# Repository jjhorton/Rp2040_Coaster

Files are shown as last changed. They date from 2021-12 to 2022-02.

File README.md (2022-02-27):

# Rp2040_Coaster

## Introduction
The idea was to build a light up drinks coaster, which would sit under a clear glass drinks bottle and light it up in a colorful display, only when the bottle is on top. 

## Building 

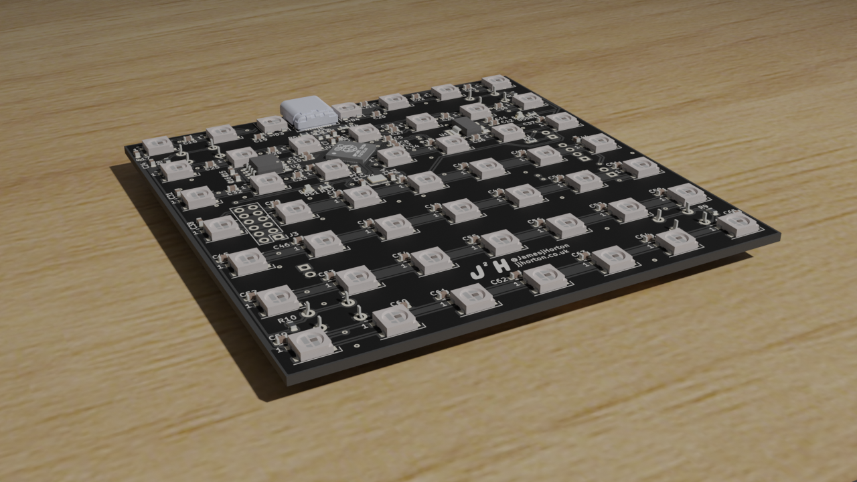
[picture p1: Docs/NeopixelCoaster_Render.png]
Render of the board in Blender


The main circuit is built around a [RP2040](https://www.raspberrypi.com/documentation/microcontrollers/rp2040.html), using the WS2812B "Neopixels" as the LEDs to create the colours, and a USB-C connector for power and programming. The PCB is designed using Kicad, and makes use of a simple 2 layer PCB, the examples here are made using JLCPCB, but any should work. 

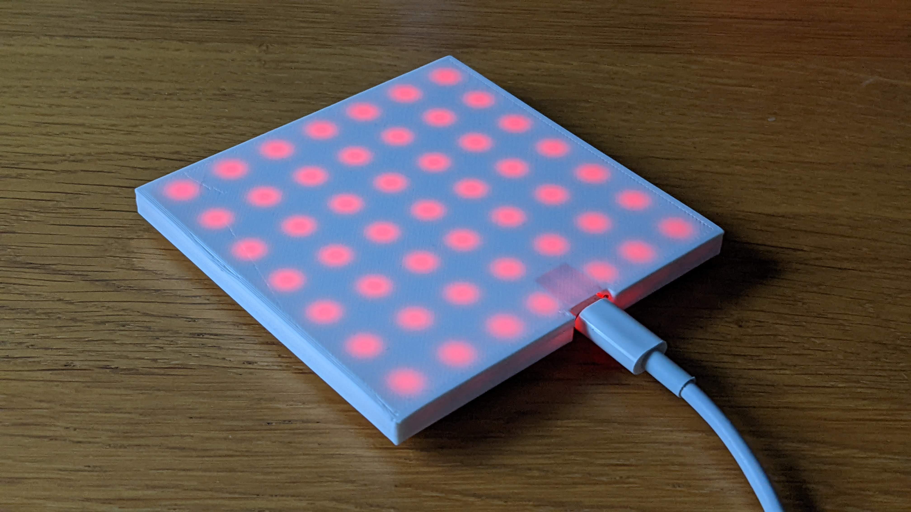
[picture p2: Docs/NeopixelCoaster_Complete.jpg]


The control software is written in C and is based of the PIO example from the Raspberry Pi example repo, the colours are generated based on the inputs of the 4 switches under the PCB. If two of the 4 switches are on, the light display begins, fading between pre-generated color pattern, which repeats. 

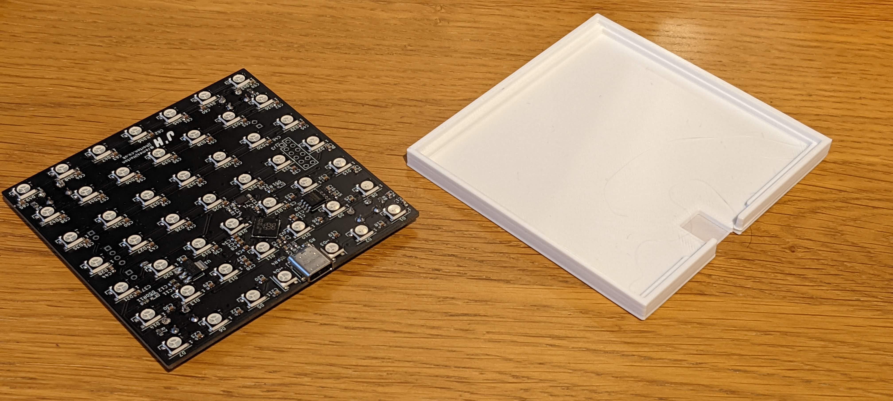
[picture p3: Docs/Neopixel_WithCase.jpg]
Final PCB with case


The PCB is placed under a 3d Printed case, this protects the PCB and electronics from any liquid or condensation on a cold bottle, the case is designed using openscad and the examples shown were printed on an Ender3 3D printed, and it should be possible to produce with most cheap 3D printers. 

## Testing

The software and PCB's fabrication files are built using Github actions, and the artifacts file contains a build of the latest software for uploading to the RP2040 and Gerbers that can be used to produced the PCB's using JLCPCB 



For the case, using the OpenSCAD files in the repo, they are automatically converted into a STL file using a seperate github workflow, with the files downloadable as an artifact from the last time they were run. 



## License 

Code: BSD-3-Clause

PCB/3D Model: CERN Open Hardware Licence Version 2 - Permissive

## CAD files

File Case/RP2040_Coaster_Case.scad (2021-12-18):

difference(){
    difference() {
        translate([0,0,-0])
            cube([95,95,7],true);
        {translate([0,0,0]) 
            cube([86,90,2.5],true);
        translate([0,0,2.5]) 
            cube([91,91,3.1],true);};
    }
    {translate([41.5,-6.61,-1.5])
        cube([13,10,3.2],true);
        
     translate([47.5,-6.61,-0.9])
        cube([3,10,3.2],true);
        
     translate([46.5,-6.61,0.9])
        cube([3,12,8],true);
        
     translate([43,-6.61,0.25])
        cube([5,30,3],true);
    }
    
}

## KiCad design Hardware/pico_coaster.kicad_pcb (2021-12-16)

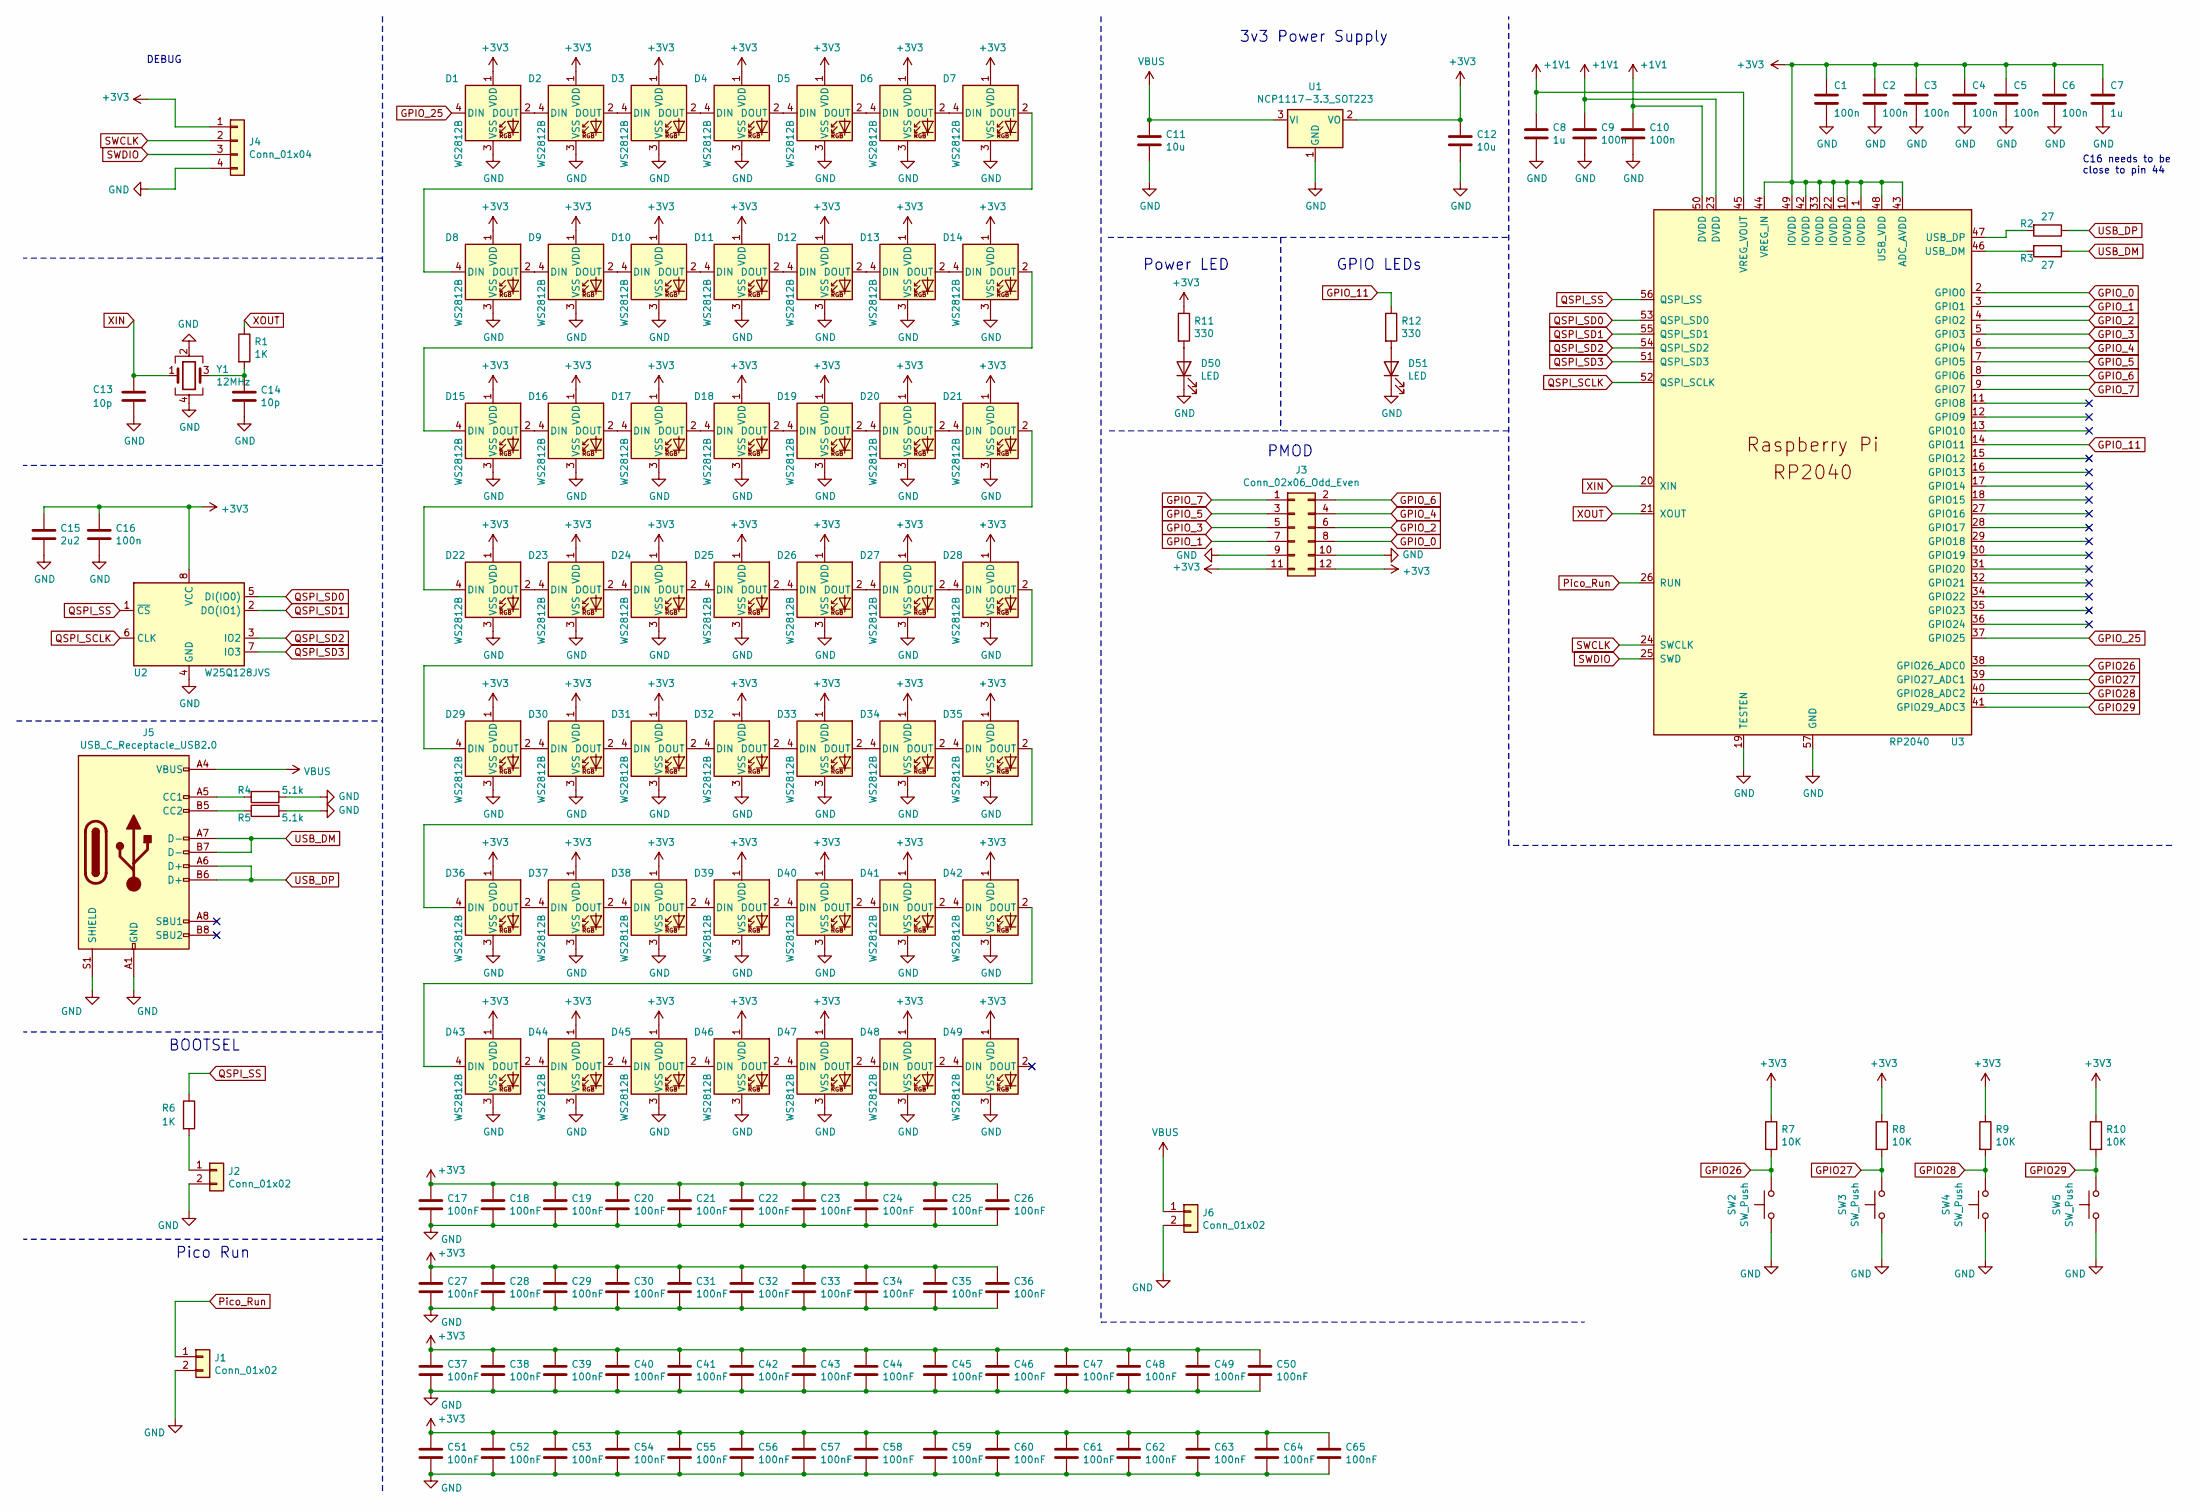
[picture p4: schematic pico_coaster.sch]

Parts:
C1, C2, C3, C4, C5, C6, C9, C10, C16: 100n; C_0603_1608Metric
C7, C8: 1u; C_0603_1608Metric
C11, C12: 10u; C_0603_1608Metric
C13, C14: 10p; C_0603_1608Metric
C15: 2u2; C_0603_1608Metric
C17, C18, C19, C20, C21, C22, C23, C24, C25, C26, C27, C28, C29, C30, C31, C32, C33, C34, C35, C36, C37, C38, C39, C40, C41, C42, C43, C44, C45, C46, C47, C48, C49, C50, C51, C52, C53, C54, C55, C56, C57, C58, C59, C60, C61, C62, C63, C64, C65: 100nF; C_0603_1608Metric
D1, D2, D3, D4, D5, D6, D7, D8, D9, D10, D11, D12, D13, D14, D15, D16, D17, D18, D19, D20, D21, D22, D23, D24, D25, D26, D27, D28, D29, D30, D31, D32, D33, D34, D35, D36, D37, D38, D39, D40, D41, D42, D43, D44, D45, D46, D47, D48, D49: WS2812B; LED_WS2812B_PLCC4_5.0x5.0mm_P3.2mm
D50, D51: LED; LED_0603_1608Metric
J1, J2, J6: Conn_01x02; PinHeader_1x02_P2.54mm_Horizontal
J3: Conn_02x06_Odd_Even; PinHeader_2x06_P2.54mm_Vertical
J4: Conn_01x04; PinHeader_1x04_P2.54mm_Vertical
J5: USB_C_Receptacle_USB2.0; USB_C_Receptacle_Amphenol_12401610E4-2A_CircularHoles
R1, R6: 1K; R_0603_1608Metric
R2, R3: 27; R_0603_1608Metric
R4, R5: 5.1k; R_0603_1608Metric
R7, R8, R9, R10: 10K; R_0603_1608Metric
R11, R12: 330; R_0603_1608Metric
SW2, SW3, SW4, SW5: SW_Push; SW_PUSH_6mm_H4.3mm
U1: NCP1117-3.3_SOT223; SOT-223-3_TabPin2
U2: W25Q128JVS; SOIC-8_5.23x5.23mm_P1.27mm
U3: RP2040; RP2040-QFN-56
Y1: 12MHz; Crystal_SMD_SeikoEpson_FA238-4Pin_3.2x2.5mm

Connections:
+1V1: C8.1, C9.1, C10.1, U3.23 (DVDD), U3.45 (VREG_VOUT), U3.50 (DVDD)
+3V3: C1.1, C2.1, C3.1, C4.1, C5.1, C6.1, C7.1, C12.1, C15.1, C16.1, C17.1, C18.1, C19.1, C20.1, C21.1, C22.1, C23.1, C24.1, C25.1, C26.1, C27.1, C28.1, C29.1, C30.1, C31.1, C32.1, C33.1, C34.1, C35.1, C36.1, C37.1, C38.1, C39.1, C40.1, C41.1, C42.1, C43.1, C44.1, C45.1, C46.1, C47.1, C48.1, C49.1, C50.1, C51.1, C52.1, C53.1, C54.1, C55.1, C56.1, C57.1, C58.1, C59.1, C60.1, C61.1, C62.1, C63.1, C64.1, C65.1, D1.1 (VDD), D2.1 (VDD), D3.1 (VDD), D4.1 (VDD), D5.1 (VDD), D6.1 (VDD), D7.1 (VDD), D8.1 (VDD), D9.1 (VDD), D10.1 (VDD), D11.1 (VDD), D12.1 (VDD), D13.1 (VDD), D14.1 (VDD), D15.1 (VDD), D16.1 (VDD), D17.1 (VDD), D18.1 (VDD), D19.1 (VDD), D20.1 (VDD), D21.1 (VDD), D22.1 (VDD), D23.1 (VDD), D24.1 (VDD), D25.1 (VDD), D26.1 (VDD), D27.1 (VDD), D28.1 (VDD), D29.1 (VDD), D30.1 (VDD), D31.1 (VDD), D32.1 (VDD), D33.1 (VDD), D34.1 (VDD), D35.1 (VDD), D36.1 (VDD), D37.1 (VDD), D38.1 (VDD), D39.1 (VDD), D40.1 (VDD), D41.1 (VDD), D42.1 (VDD), D43.1 (VDD), D44.1 (VDD), D45.1 (VDD), D46.1 (VDD), D47.1 (VDD), D48.1 (VDD), D49.1 (VDD), J3.11, J3.12, J4.1, R7.1, R8.1, R9.1, R10.1, R11.1, U1.2 (VO), U2.8 (VCC), U3.1 (IOVDD), U3.10 (IOVDD), U3.22 (IOVDD), U3.33 (IOVDD), U3.42 (IOVDD), U3.43 (ADC_AVDD), U3.44 (VREG_IN), U3.48 (USB_VDD), U3.49 (IOVDD)
GND: C1.2, C2.2, C3.2, C4.2, C5.2, C6.2, C7.2, C8.2, C9.2, C10.2, C11.2, C12.2, C13.2, C14.2, C15.2, C16.2, C17.2, C18.2, C19.2, C20.2, C21.2, C22.2, C23.2, C24.2, C25.2, C26.2, C27.2, C28.2, C29.2, C30.2, C31.2, C32.2, C33.2, C34.2, C35.2, C36.2, C37.2, C38.2, C39.2, C40.2, C41.2, C42.2, C43.2, C44.2, C45.2, C46.2, C47.2, C48.2, C49.2, C50.2, C51.2, C52.2, C53.2, C54.2, C55.2, C56.2, C57.2, C58.2, C59.2, C60.2, C61.2, C62.2, C63.2, C64.2, C65.2, D1.3 (VSS), D2.3 (VSS), D3.3 (VSS), D4.3 (VSS), D5.3 (VSS), D6.3 (VSS), D7.3 (VSS), D8.3 (VSS), D9.3 (VSS), D10.3 (VSS), D11.3 (VSS), D12.3 (VSS), D13.3 (VSS), D14.3 (VSS), D15.3 (VSS), D16.3 (VSS), D17.3 (VSS), D18.3 (VSS), D19.3 (VSS), D20.3 (VSS), D21.3 (VSS), D22.3 (VSS), D23.3 (VSS), D24.3 (VSS), D25.3 (VSS), D26.3 (VSS), D27.3 (VSS), D28.3 (VSS), D29.3 (VSS), D30.3 (VSS), D31.3 (VSS), D32.3 (VSS), D33.3 (VSS), D34.3 (VSS), D35.3 (VSS), D36.3 (VSS), D37.3 (VSS), D38.3 (VSS), D39.3 (VSS), D40.3 (VSS), D41.3 (VSS), D42.3 (VSS), D43.3 (VSS), D44.3 (VSS), D45.3 (VSS), D46.3 (VSS), D47.3 (VSS), D48.3 (VSS), D49.3 (VSS), D50.1 (K), D51.1 (K), J1.2, J2.2, J3.9, J3.10, J4.4, J5.A1 (GND), J5.A12 (GND), J5.B1 (GND), J5.B12 (GND), J5.S1 (SHIELD), J6.2, R4.1, R5.2, SW2.1, SW3.1, SW4.1, SW5.1, U1.1 (GND), U2.4 (GND), U3.19 (TESTEN), U3.57 (GND), Y1.2, Y1.4
GPIO26: R7.2, SW2.2, U3.38 (GPIO26_ADC0)
GPIO27: R8.2, SW3.2, U3.39 (GPIO27_ADC1)
GPIO28: R9.2, SW4.2, U3.40 (GPIO28_ADC2)
GPIO29: R10.2, SW5.2, U3.41 (GPIO29_ADC3)
GPIO_0: J3.8, U3.2 (GPIO0)
GPIO_1: J3.7, U3.3 (GPIO1)
GPIO_2: J3.6, U3.4 (GPIO2)
GPIO_3: J3.5, U3.5 (GPIO3)
GPIO_4: J3.4, U3.6 (GPIO4)
GPIO_5: J3.3, U3.7 (GPIO5)
GPIO_6: J3.2, U3.8 (GPIO6)
GPIO_7: J3.1, U3.9 (GPIO7)
GPIO_11: R12.1, U3.14 (GPIO11)
GPIO_25: D1.4 (DIN), U3.37 (GPIO25)
unnamed: C14.1, R1.2, Y1.3
unnamed: D1.2 (DOUT), D2.4 (DIN)
unnamed: D2.2 (DOUT), D3.4 (DIN)
unnamed: D3.2 (DOUT), D4.4 (DIN)
unnamed: D4.2 (DOUT), D5.4 (DIN)
unnamed: D5.2 (DOUT), D6.4 (DIN)
unnamed: D6.2 (DOUT), D7.4 (DIN)
unnamed: D7.2 (DOUT), D8.4 (DIN)
unnamed: D8.2 (DOUT), D9.4 (DIN)
unnamed: D10.2 (DOUT), D11.4 (DIN)
unnamed: D9.2 (DOUT), D10.4 (DIN)
unnamed: D11.2 (DOUT), D12.4 (DIN)
unnamed: D12.2 (DOUT), D13.4 (DIN)
unnamed: D13.2 (DOUT), D14.4 (DIN)
unnamed: D14.2 (DOUT), D15.4 (DIN)
unnamed: D15.2 (DOUT), D16.4 (DIN)
unnamed: D16.2 (DOUT), D17.4 (DIN)
unnamed: D17.2 (DOUT), D18.4 (DIN)
unnamed: D18.2 (DOUT), D19.4 (DIN)
unnamed: D19.2 (DOUT), D20.4 (DIN)
unnamed: D20.2 (DOUT), D21.4 (DIN)
unnamed: D21.2 (DOUT), D22.4 (DIN)
unnamed: D22.2 (DOUT), D23.4 (DIN)
unnamed: D23.2 (DOUT), D24.4 (DIN)
unnamed: D24.2 (DOUT), D25.4 (DIN)
unnamed: D25.2 (DOUT), D26.4 (DIN)
unnamed: D26.2 (DOUT), D27.4 (DIN)
unnamed: D27.2 (DOUT), D28.4 (DIN)
unnamed: D28.2 (DOUT), D29.4 (DIN)
unnamed: D29.2 (DOUT), D30.4 (DIN)
unnamed: D30.2 (DOUT), D31.4 (DIN)
unnamed: D31.2 (DOUT), D32.4 (DIN)
unnamed: D32.2 (DOUT), D33.4 (DIN)
unnamed: D33.2 (DOUT), D34.4 (DIN)
unnamed: D34.2 (DOUT), D35.4 (DIN)
unnamed: D35.2 (DOUT), D36.4 (DIN)
unnamed: D36.2 (DOUT), D37.4 (DIN)
unnamed: D37.2 (DOUT), D38.4 (DIN)
unnamed: D38.2 (DOUT), D39.4 (DIN)
unnamed: D39.2 (DOUT), D40.4 (DIN)
unnamed: D40.2 (DOUT), D41.4 (DIN)
unnamed: D41.2 (DOUT), D42.4 (DIN)
unnamed: D42.2 (DOUT), D43.4 (DIN)
unnamed: D43.2 (DOUT), D44.4 (DIN)
unnamed: D44.2 (DOUT), D45.4 (DIN)
unnamed: D45.2 (DOUT), D46.4 (DIN)
unnamed: D46.2 (DOUT), D47.4 (DIN)
unnamed: D47.2 (DOUT), D48.4 (DIN)
unnamed: D48.2 (DOUT), D49.4 (DIN)
unnamed: D50.2 (A), R11.2
unnamed: D51.2 (A), R12.2
unnamed: J2.1, R6.2
unnamed: J5.A5 (CC1), R4.2
unnamed: J5.B5 (CC2), R5.1
unnamed: R2.2, U3.47 (USB_DP)
unnamed: R3.2, U3.46 (USB_DM)
Pico_Run: J1.1, U3.26 (RUN)
QSPI_SCLK: U2.6 (CLK), U3.52 (QSPI_SCLK)
QSPI_SD0: U2.5 (DI(IO0)), U3.53 (QSPI_SD0)
QSPI_SD1: U2.2 (DO(IO1)), U3.55 (QSPI_SD1)
QSPI_SD2: U2.3 (IO2), U3.54 (QSPI_SD2)
QSPI_SD3: U2.7 (IO3), U3.51 (QSPI_SD3)
QSPI_SS: R6.1, U2.1 (~CS), U3.56 (QSPI_SS)
SWCLK: J4.2, U3.24 (SWCLK)
SWDIO: J4.3, U3.25 (SWD)
USB_DM: J5.A7 (D-), J5.B7 (D-), R3.1
USB_DP: J5.A6 (D+), J5.B6 (D+), R2.1
VBUS: C11.1, J5.A4 (VBUS), J5.A9 (VBUS), J5.B4 (VBUS), J5.B9 (VBUS), J6.1, U1.3 (VI)
XIN: C13.1, U3.20 (XIN), Y1.1
XOUT: R1.1, U3.21 (XOUT)

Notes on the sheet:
PMOD
Pico Run
BOOTSEL
DEBUG
C16 needs to be close to pin 44
3v3 Power Supply
GPIO LEDs
Power LED

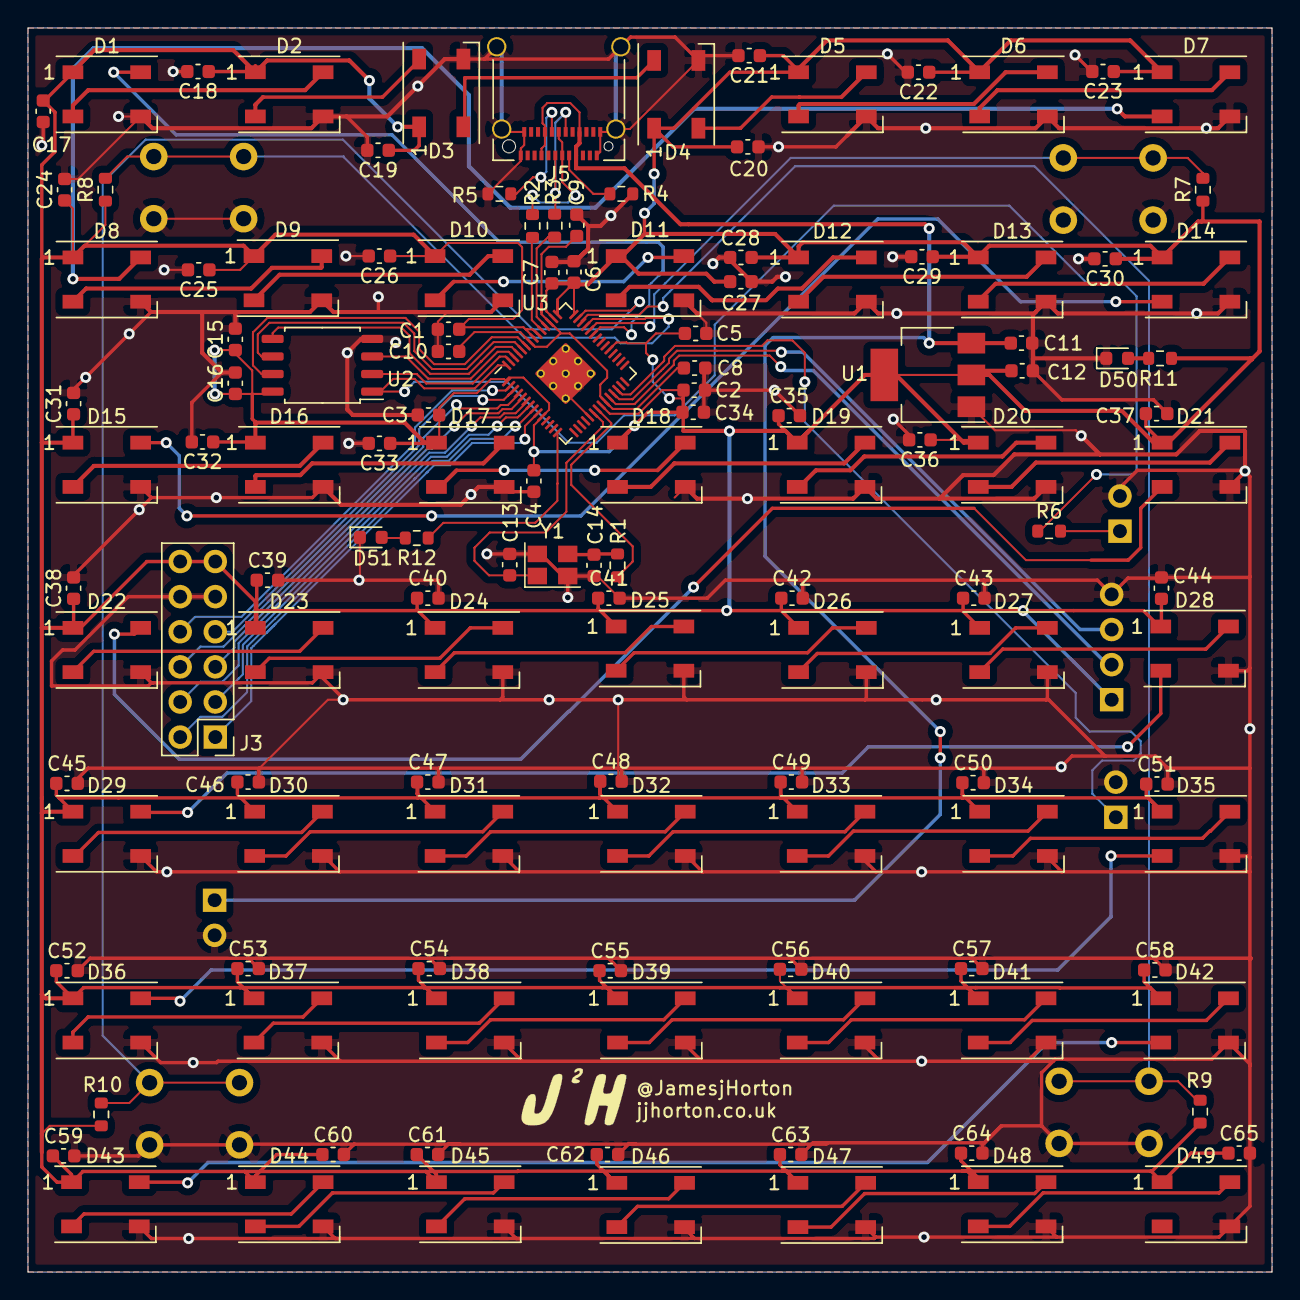
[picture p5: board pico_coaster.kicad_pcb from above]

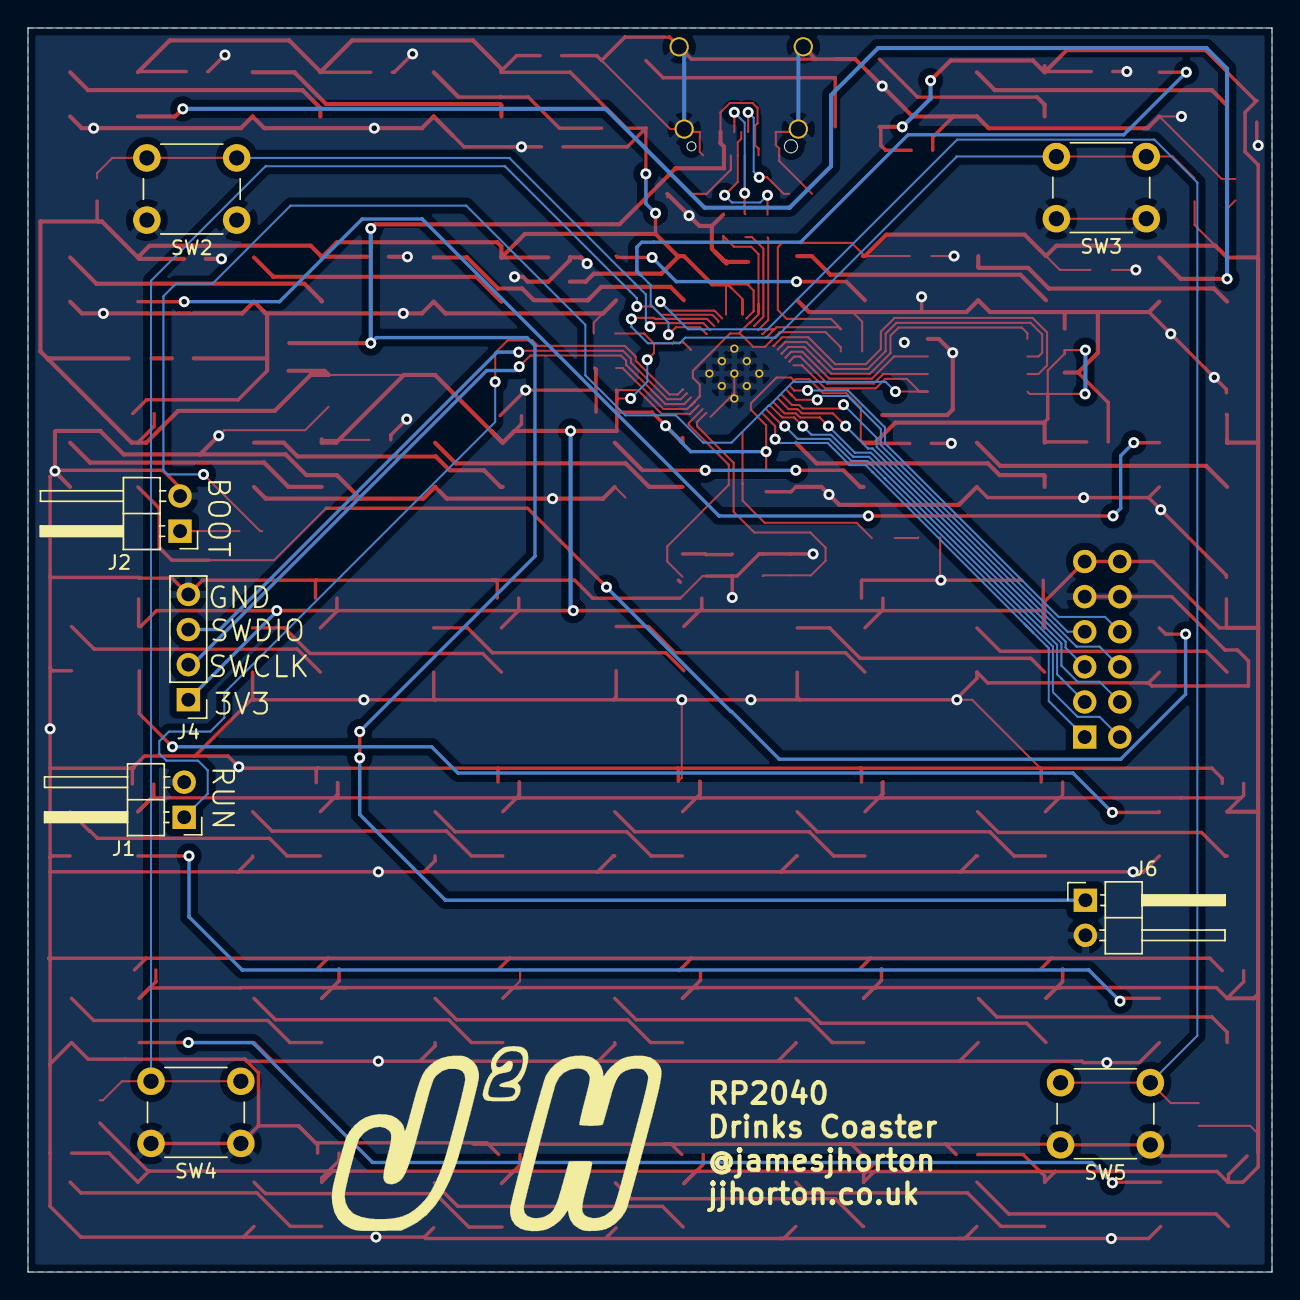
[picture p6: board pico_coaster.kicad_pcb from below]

Board: 2 copper layers, 90.0 x 90.0 mm, 142 parts (8 on the bottom side), 87 nets.

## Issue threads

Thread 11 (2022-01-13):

Comple Readme file

jjhorton, 2022-01-13:
Add details on the board to the README file:

- [ ] Photos of the PCB
- [ ] Photos of the whole setup
- [ ] Description of building the software
- [ ] Description of the Hardware
- [ ] Description of printing the Case

Closed 2022-02-27.

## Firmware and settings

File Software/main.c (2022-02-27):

/**
 * RP2040 Coaster code 
 * WS2812 code base from https://github.com/raspberrypi/pico-examples
 * Copyright (c) 2022 James Horton
 * Copyright (c) 2020 Raspberry Pi (Trading) Ltd.
 *
 * SPDX-License-Identifier: BSD-3-Clause
 */

#include <stdio.h>
#include <stdlib.h>

#include "pico/stdlib.h"
#include "hardware/pio.h"
#include "hardware/clocks.h"
#include "ws2812.pio.h"

const int RGB_LOOKUP[][3] = {{255,14,240},{255,13,240},{255,12,240},{255,11,240},
														{255,10,240},{255,9,240},{255,8,240},{255,7,240},
														{255,6,240},{255,5,240},{255,4,240},{255,3,240},
														{255,2,240},{255,1,240},{255,0,240},{255,0,224},
														{255,0,208},{255,0,192},{255,0,176},{255,0,160},
														{255,0,144},{255,0,128},{255,0,112},{255,0,96 },
														{255,0,80 },{255,0,64 },{255,0,48 },{255,0,32 },
														{255,0,16 },{255,0,0  },{255,10,0 },{255,20,0 },
														{255,30,0 },{255,40,0 },{255,50,0 },{255,60,0 },
														{255,70,0 },{255,80,0 },{255,90,0 },{255,100,0},
														{255,110,0},{255,120,0},{255,130,0},{255,140,0},
														{255,150,0},{255,160,0},{255,170,0},{255,180,0},
														{255,190,0},{255,200,0},{255,210,0},{255,220,0},
														{255,230,0},{255,240,0},{255,250,0},{253,255,0},
														{215,255,0},{176,255,0},{138,255,0},{101,255,0},
														{62,255,0 },{23,255,0 },{0,255,16 },{0,255,54 },
														{0,255,92 },{0,255,131},{0,255,168},{0,255,208},
														{0,255,244},{0,228,255},{0,212,255},{0,196,255},
														{0,180,255},{0,164,255},{0,148,255},{0,132,255},
														{0,116,255},{0,100,255},{0,84,255 },{0,68,255 },
														{0,50,255 },{0,34,255 },{0,18,255 },{0,2,255  },
														{0,0,255  },{1,0,255  },{2,0,255  },{3,0,255  },
														{4,0,255  },{5,0,255 }};

static inline void put_pixel(uint32_t pixel_grb) {
    pio_sm_put_blocking(pio0, 0, pixel_grb << 8u);
}

static inline uint32_t urgb_u32(uint8_t r, uint8_t g, uint8_t b) {
    return
            ((uint32_t) (r) << 8) |
            ((uint32_t) (g) << 16) |
            (uint32_t) (b);
}

int valueinarray(int val, int arr[], int len){
    int i;
    for(i = 0; i < len; i++){
        if(arr[i] == val) return 1;
    }
    return 0;
}

void setcenter(int red, int green, int blue){
		int inner[] = {16,17,18,23,24,25,30,31,32};
		int inner_len = sizeof(inner) / sizeof(inner[0]);

		int outer[] = {0,1,2,3,4,5,6,7,13,14,20,21,27,28,34,35,41,42,43,44,45,46,47,48};
		int outer_len = sizeof(outer) / sizeof(outer[0]);

		for (int i = 0; i < (49); ++i){
			if (valueinarray(i, inner, inner_len)) {
				put_pixel(urgb_u32(red,green,blue));
			}
			else {
				if (valueinarray(i, outer, outer_len)) {
					put_pixel(urgb_u32(0,4,0));
				}
				else{
				put_pixel(urgb_u32(0,0,0));
				}
			}
		}
		sleep_ms(100);
}

void setoutside(int red, int green, int blue){

		int outer[] = {0,1,2,3,4,5,6,7,13,14,20,21,27,28,34,35,41,42,43,44,45,46,47,48};
		int outer_len = sizeof(outer) / sizeof(outer[0]);

		for (int i = 0; i < (49); ++i){
			if (valueinarray(i, outer, outer_len)) {
				put_pixel(urgb_u32(red,green,blue));
			}
			else {
				put_pixel(urgb_u32(0,0,0));
			}
		}
		sleep_ms(100);
}

void set_blank(int led_num){
		sleep_ms(50);

		for (int i = 0; i < (led_num); ++i){
			put_pixel(urgb_u32(0,0,0));
		}
		sleep_ms(100);
}

void set_colour(int led_num, int red, int green, int blue){
		sleep_ms(50);

		for (int i = 0; i < (led_num); ++i){
			put_pixel(urgb_u32(red,green,blue));
		}
		sleep_ms(100);
}

const int PIN_TX = 25;

int main() {

		const uint BUTTON_PINS[] = {26,27,28,29};

		for(int x = 0; x<4; x++) {
			gpio_init(BUTTON_PINS[x]);
			gpio_set_dir(BUTTON_PINS[x], GPIO_IN);
		}

    //set_sys_clock_48();
    stdio_init_all();

    PIO pio = pio0;
    int sm = 0;

    uint offset = pio_add_program(pio, &ws2812_program);
    ws2812_program_init(pio, sm, offset, PIN_TX, 800000, false);

    int t = 0;
		int len = 49;


		//Set all LED's to be off
		for (int i = 0; i < (len); ++i) {
				put_pixel(urgb_u32(0, 0, 0));
		}
		sleep_ms(100);

		while(1) {

			for(int level = 0; level<180; level++ ){

						int my_test = 0;
						for (int i = 0; i < (4); ++i) {
							if(gpio_get(BUTTON_PINS[i])!=1){
									my_test++;
							}
						}

						//Set the center LED's
						if(my_test>2){
							if (level < 90) {
								setcenter(RGB_LOOKUP[level][0], RGB_LOOKUP[level][1], RGB_LOOKUP[level][2]);
							}
							else {
								int pos = 179 - level;
								setcenter(RGB_LOOKUP[pos][0], RGB_LOOKUP[pos][1], RGB_LOOKUP[pos][2]);

							}

						}
						else{
							//setcenter(red, green, blue);
							set_colour(49,2,0,0);
							//setoutside(2,0,0);
						}

			}


		}

}

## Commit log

2021-10-10 Pervious schematic and layout
    [pico_coaster.kicad_pcb, pico_coaster.sch]
2021-10-10 reduce Pmod connectors from 3 to 1
    [pico_coaster.sch]
2021-10-10 Add the workflow file for the PCB and software
2021-11-12 prior layout changes
    [pico_coaster.kicad_pcb]
2021-11-12 add USB-c connector on top layer
    [pico_coaster.kicad_pcb]
2021-11-12 route the Resistors for the USB Connector
    [pico_coaster.kicad_pcb]
2021-11-12 Routing RP2040 Caps, Memory and PMod Connector
    [pico_coaster.kicad_pcb]
2021-11-12 Route the GPIO buttons
    [pico_coaster.kicad_pcb]
2021-11-12 Routing Bottom row of RGB LEDs
    [pico_coaster.kicad_pcb]
2021-11-12 Routing Bottom row 3 RGB LEDs completed
    [pico_coaster.kicad_pcb]
2021-11-12 Finish layout for the top three LED rows
    [pico_coaster.kicad_pcb, pico_coaster.sch]
2021-11-12 Swap Boot/Run buttons for pin headers
    [pico_coaster.kicad_pcb, pico_coaster.sch]
2021-11-12 fix missing 3v3 connection
    [pico_coaster.kicad_pcb]
2021-11-12 add front gnd fill zone and logo on front
    [pico_coaster.kicad_pcb]
2021-11-12 Fix DRC errors
    [pico_coaster.kicad_pcb, pico_coaster.sch]
2021-11-12 fix unconnected DRC errors
    [pico_coaster.kicad_pcb]
2021-11-12 Add LED flash as basic software for CI to pass
2021-11-12 fix type in gpio_init()
    [main.c]
2021-11-12 fix error with brackets
    [main.c]
2021-11-14 Add 2.54mm power in connector
    [pico_coaster.kicad_pcb, pico_coaster.sch]
2021-11-14 update chematic with number
    [pico_coaster.sch]
2021-11-26 redraw rear ground plane
    [pico_coaster.kicad_pcb]
2021-11-26 relocate gnd via near signal path
    [pico_coaster.kicad_pcb]
2021-11-28 Update the software to have random colours on button press
2021-12-01 and set functions and use button control
2021-12-16 change clk capasitors
    [pico_coaster.sch]
2021-12-16 update cap values in pcb file
    [pico_coaster.kicad_pcb]
2021-12-18 adjust USB port size and hight of sides
    [RP2040_Coaster_Case.scad]
